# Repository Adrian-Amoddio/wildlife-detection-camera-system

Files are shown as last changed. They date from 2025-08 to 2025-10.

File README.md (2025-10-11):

# Wildlife Camera System



## Demo Video

Watch the demo (https://youtu.be/tZjDdPRHNxE)  
[▶ **Watch on YouTube**](https://youtu.be/tZjDdPRHNxE)

I designed and built a fully off grid, solar powered wildlife monitoring system. It can stream live video, log environmental data, and trigger my Canon EOS R6 for high-resolution stills remotely from anywhere with mobile reception.

The system operates with a Raspberry Pi 5, Python/Flask backend, a React dashboard for camera / mode control and monitoring, and an AWS EC2 instance for streaming with a dockerized NGINX server with RTMP to HLS conversion. I created everything myself and handled: picking the hardware, designing and fabricating the case, electronics wiring, networking, coding the APIs, and coding the front end website.

The goal was to create a drop and leave anywhere device for photographing and researching wildlife in places that are hard to reach without having to hike back in to retrieve data or pickup heavy gear.

As an improvement to the project, I recently added a YOLOv8 animal detection prototype script that can detect various species of wildlife. Once deployed to the Pi, the system has the potential to selectively take photographs only of animals of interest and categorise them accordingly.

Tech Summary: Raspberry Pi 5, Python, Flask, React, AWS EC2, Docker, NGINX RTMP/HLS, I²C sensor integration, Linux, CAD, Hands on Fabrication

---

## Tech Stack

- **Hardware:** Raspberry Pi 5 (8GB), Pi Camera Module 3 Wide, Canon EOS R6 , PicoDev BMP280 sensor
- **Pi software:** Python 3.11, `libcamera`, `ffmpeg`, `gphoto2`
- **Backend (EC2):** Dockerized NGINX RTMP/HLS streaming server, Flask API for recieving sensor data
- **Frontend:** React with Recharts, live video stream, environmental telemetry, Canon R6 capture, able to toggle modes
- **Protocols:** RTMP to HLS, REST (JSON), I²C
- **Power and Enclosure:** LiFePO₄ battery, solar panel, custom lens port and weather proof case

---

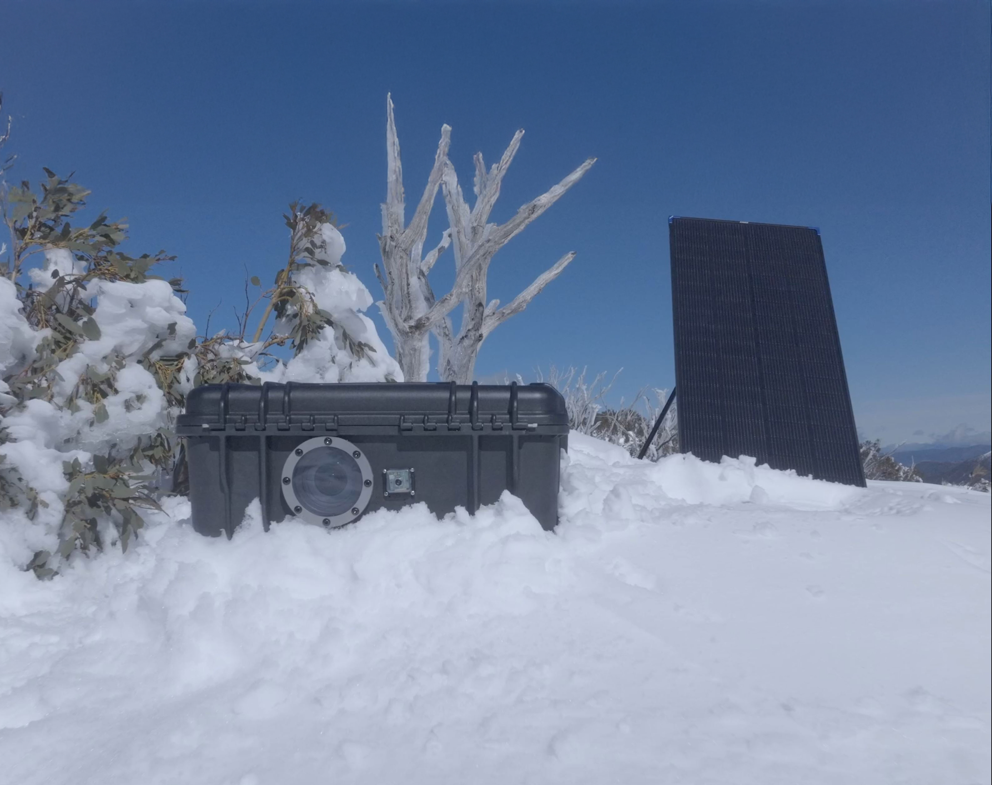
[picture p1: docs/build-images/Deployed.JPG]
Build photo
## 

### Final UI Screenshots

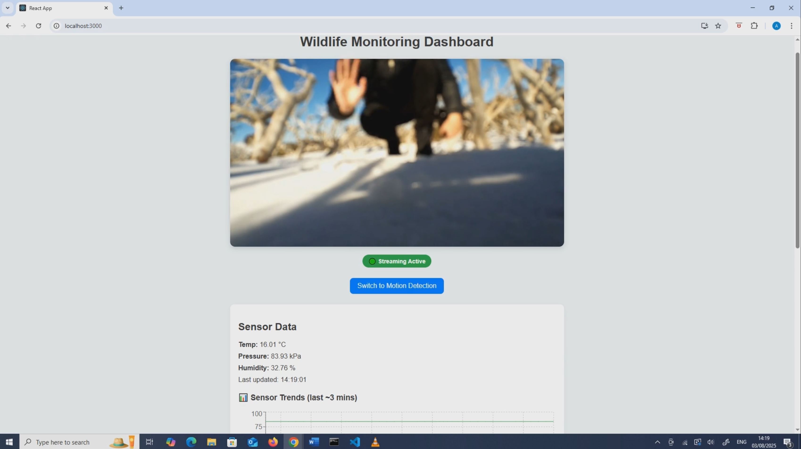
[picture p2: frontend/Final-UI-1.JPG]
Final UI - Stream View

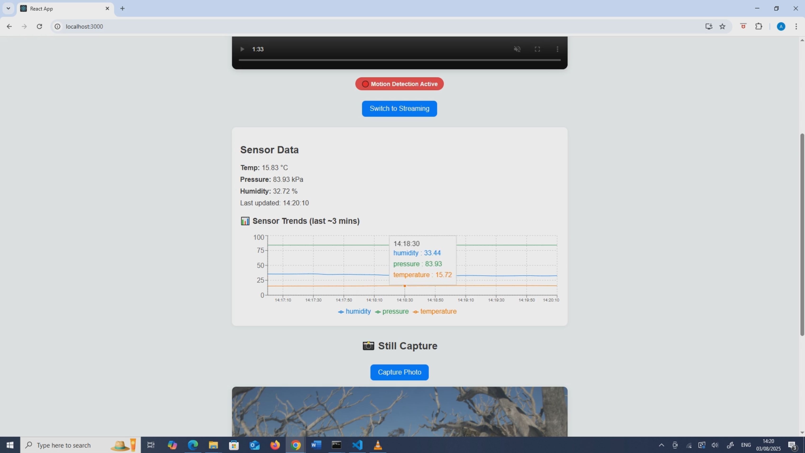
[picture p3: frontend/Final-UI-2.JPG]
Final UI - Sensor Data

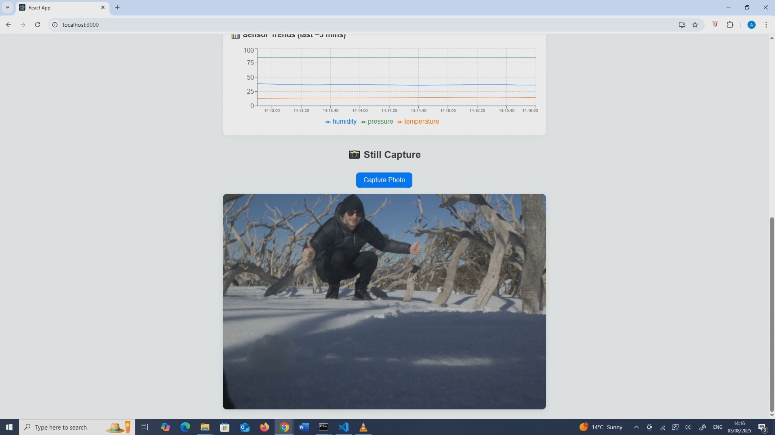
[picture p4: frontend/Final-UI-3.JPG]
Final UI - Capture Function


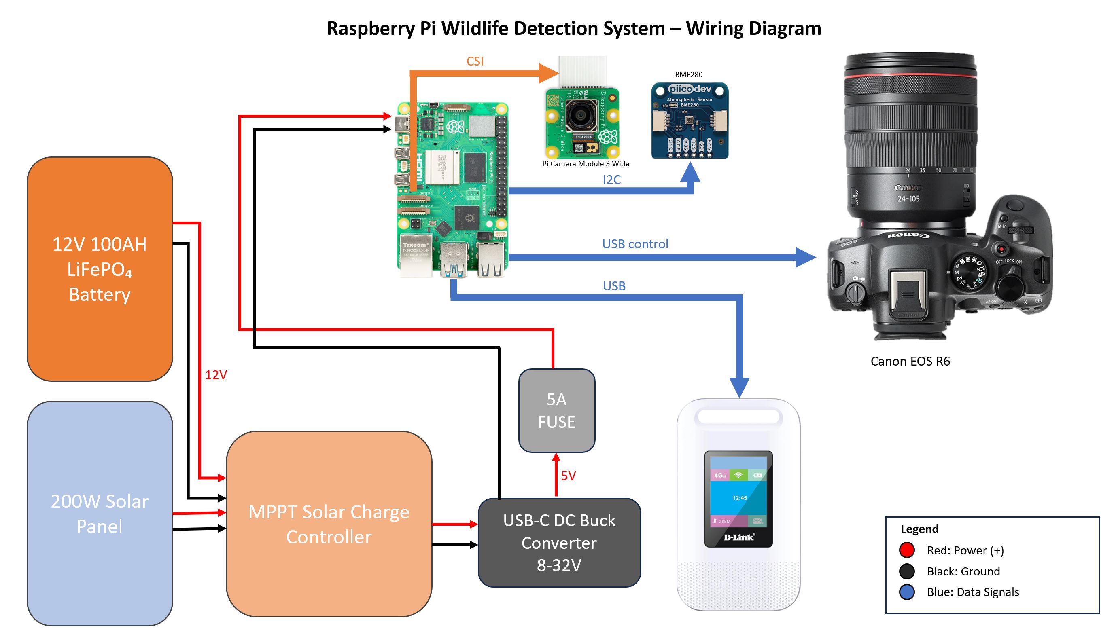
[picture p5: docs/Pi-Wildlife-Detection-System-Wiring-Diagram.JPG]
Wiring Diagram
## 

---

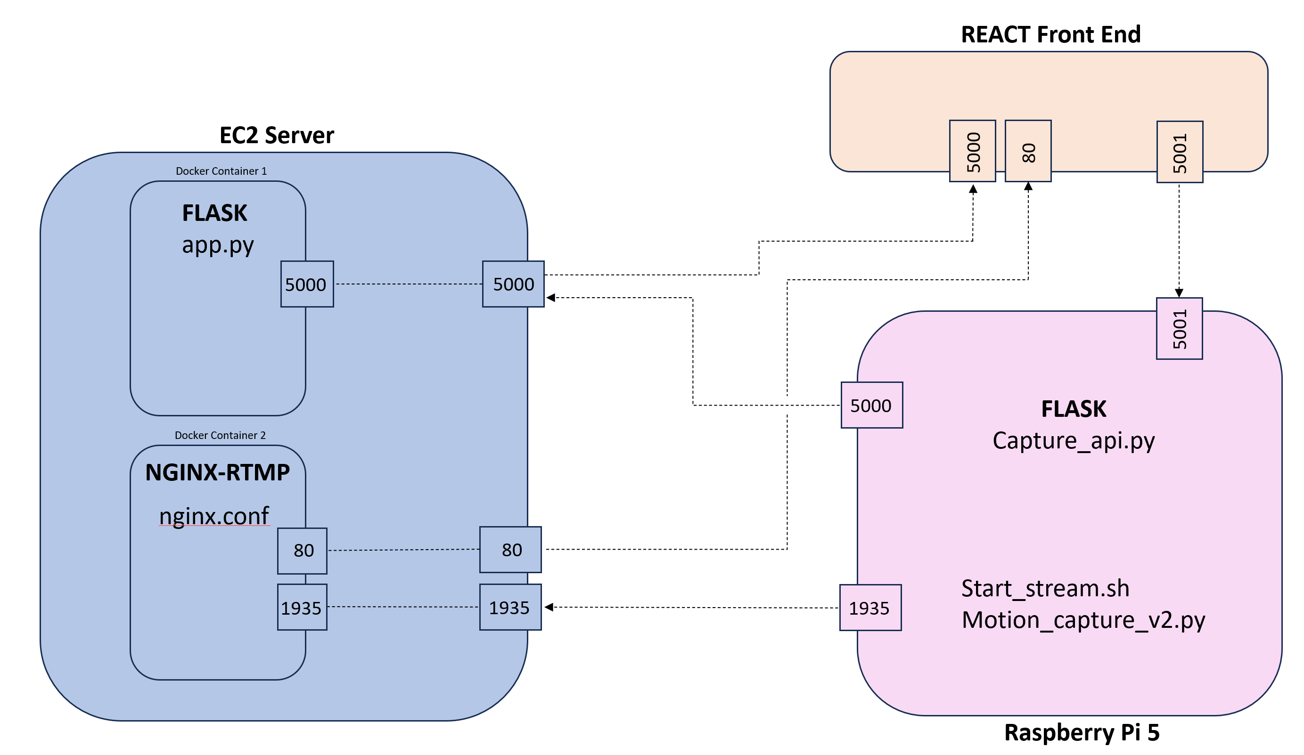
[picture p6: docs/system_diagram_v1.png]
Data Flow Diagram
## 

---

## What it does

- **Live stream**: Low-latency HLS stream from the Pi → EC2 → React front end
- **Motion detection**: Triggers the R6 for high-resolution stills (or you can capture manually).
- **Telemetry**: Temperature, pressure, humidity via BMP280 with charts where you can view the data.
- **Mode switching**: Toggle **Motion** ↔ **Streaming** from the dashboard.
- **Smart and Reliable UX**: Sensor polling, stream retry logic, and clear error states in the UI.

> **My role:** I designed and implemented the **entire system**—hardware choices, enclosure, Pi scripts, EC2 services, and the React frontend.

---

## AI Object Detection Prototype

To extend the system toward AI integration, I added a prototype object detection module using [YOLOv8](https://github.com/ultralytics/ultralytics).  
This prototype demonstrates how the camera feed could be enhanced with real-time wildlife recognition.

- **Model:** YOLOv8n 
- **Demo:** Script run on sample animal images, with annotated outputs saved in [`object_detection/runs/detect/pi_demo`](object_detection/runs/detect/pi_demo)  
- **Future plan:** Deploy YOLO models directly on the Raspberry Pi or stream frames to the EC2 server. Fine-tune models for Australian wildlife species (e.g. deer, snow fox, wombats, bird species).

**Example output:**

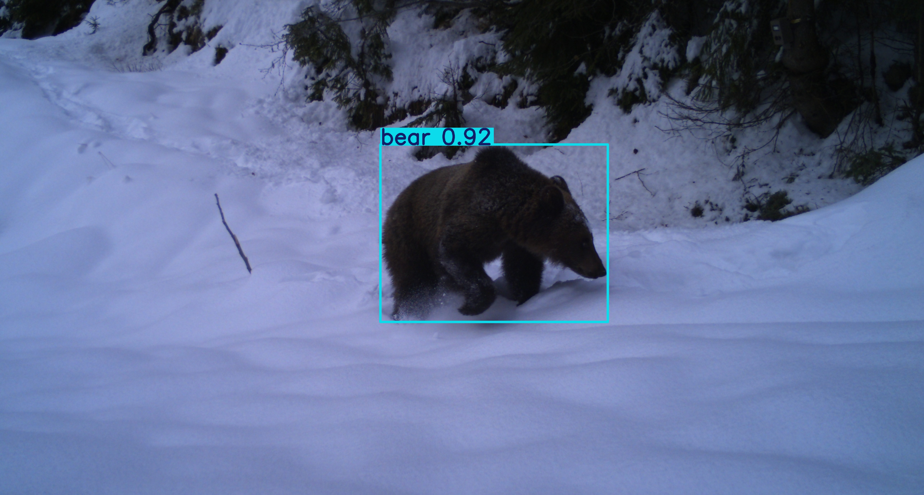
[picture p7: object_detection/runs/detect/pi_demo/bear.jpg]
Object Detection Example


---

## Project Structure

```
├── captures/                     # Optional saved test images or videos
│
├── docs/                          # Build images and final deployed photograph
│   ├── Pi-Wildlife-Detection-System-Wiring-Diagram.JPG
│   └── build-images/
│       ├── 1.jpg … 40.jpg
│       ├── AlFlange.JPG
│       └── Deployed.JPG
│
├── ec2-server/                    # Backend scripts and dockerfile for video stream and sensor data
│   ├── environmental_sensor/      # Flask API for sending BMP280 sensor data to the EC2 server
│   │   ├── app.py
│   │   ├── Dockerfile.txt
│   │   └── requirements.txt
│   │
│   └── nginx-rtmp/                 # RTMP/HLS server
│       ├── docker-compose.yml
│       ├── nginx.conf
│       └── nginx-hls/              # RTMP to HLS Docker build for NGINX
│
├── frontend/                      # Front End React Website
│   └── react-frontend/
│       ├── player.html
│       ├── styles.css
│       └── pi-stream-ui/
│           ├── .env.example
│           ├── package.json
│           ├── public/
│           └── src/
│
├── object_detection/            # Inludes sample images and results that demo the animal detection model
│   ├── runs/
│   ├── samples/
│   └── detect.py

├── hardware/                      # CAD/drawings for custom lens port for Canon R6
│   ├── acrylic-flange-files/
│   ├── aluminium-flange-files/
│   └── pmma-flange-files/
│
└── pi/                            # All scripts that run on the Pi for the different functions of the device
    ├── capture_api.py              # Remote still photo capture with the Canon EOS R6
    ├── motion_trigger_picamera2.py # Motion detection script that triggers the R6
    ├── send_sensor_data.py         # Sends sensor data to the EC2 backend
    ├── start_stream.sh             # Used whenever the user switches into streaming mode. Cannot run when other scripts are accessing the pi camera 3 wide
    └── requirements.txt
```

---

## Hardware

- Raspberry Pi 5 8GB
- Pi Camera Module 3 Wide
- Canon EOS R6 with 24–70mm f2.8 RF lens
- Picodev BMP280 environmental sensor
- D-Link Cat6 Mobile Hotspot
- Kings 12V LiFePO4 battery
- Kings 200W Solar Panel
- Kings Anderson Solar Extension Cable
- Dune MPPT Solar Charge Controller
- Tactix Black Extra Large Tough Case
- Custom camera lens port (see `/hardware/`)
- 2 × 6mm Waterproof cable glands

---

## Software

- Raspberry Pi OS (Bookworm or later, 64-bit)
- Python 3.11+
- `libcamera`
- `gphoto2`
- `ffmpeg`
- AWS EC2 backend (NGINX RTMP/HLS + Flask API)

---

## Installation

1. **Clone this repository** onto your Pi 5:

   ```bash
   git clone https://github.com/Adrian-Amoddio/wildlife-detection-camera-system.git
   cd wildlife-detection-camera-system/pi
   ```

2. **Install Python dependencies**:

   ```bash
   python3 -m venv venv
   source venv/bin/activate
   pip install -r requirements.txt
   ```

3. **Install system dependencies**:

   ```bash
   sudo apt update
   sudo apt install ffmpeg gphoto2 python3-pip libatlas-base-dev
   ```

4. **Configure environmental sensor**:

   - Ensure the BMP280 is connected via I²C
   - Enable I2C on the Pi:
     ```bash
     sudo raspi-config
     # Interfacing Options - I2C - Enable
     ```
   - Verify it’s detected:
     ```bash
     sudo apt install -y i2c-tools
     i2cdetect -y 1
     ```

5. **Set environment variables** (optional):
   - Create a `.env` file:
     ```bash
     SENSOR_API_URL=https://<ec2-server-ip>/sensor
     RTMP_SERVER_URL=rtmp://<ec2-server-ip>/live/stream
     ```

---

## Scripts Overview

- **capture_api.py** – Flask API to trigger still capture from the Canon EOS R6. Then return and save the image.
- **motion_trigger_picamera2.py** – Uses Pi Camera Module 3 Wide for motion detection to trigger R6 still capture or switch to streaming.
- **send_sensor_data.py** – Reads temperature, pressure, and humidity from BMP280 and sends JSON to EC2 backend every 10 seconds.
- **start_stream.sh** – Launches live streaming pipeline and sends to EC2 instance.

---

## Usage

### Start live stream

```bash
chmod +x start_stream.sh
./start_stream.sh
```

### Run environmental sensor loop

```bash
python3 send_sensor_data.py
```

### Run motion detection

```bash
python3 motion_trigger_picamera2.py
```

### Start capture API server

```bash
python3 capture_api.py
```

Trigger remote capture:

```bash
curl -X POST http://<pi-ip>:5000/capture
```

---

## Recommended Deployment

The scripts below need to be run on boot if you want the system to operate independantly. It is recommended you do this as running anything manually in remote areas is difficult.

- `capture_api.py`
- `send_sensor_data.py`

---

## Streaming Pipeline (RTMP converted to HLS)

The Pi streams video via **RTMP** to an **NGINX server** running on my EC2 instance. This server is inside a Docker container and uses the **NGINX RTMP module** to convert the incoming stream into **HLS**. The frontend React app then pulls the `.m3u8` playlist from the server to display the live video in the browser. The reason why I converted the stream from RTMP to HLS is because browsers do not natively support RTMP streams. HLS is natively supported in most browsers.

- The NGINX config and Docker setup are located in `ec2-server/nginx-rtmp/`
- The stream can be viewed from anywhere by accessing the React frontend
- During local testing, I used a prebuilt Windows release of NGINX with RTMP from [Broukmiken/Nginx.exe-RTMP](https://github.com/Broukmiken/Nginx.exe-32-and-64-bits-With-RTMP/releases/tag/v1.24.4) for fast iteration before deploying the Docker version to AWS

---

## Notes

- The motion detection and video screaming scripts cannot run simultanously. Only one can run at a time other wise this will cause an error or the pi will crash
- Canon EOS R6 must be powered on and connect with a USB to the Pi
- Ensure the EC2 instance is running before running any scripts on the pi or trying to access the front end.

---

## Personal Note

I am an engineer with a passion for embedded systems and photography. I wanted to make this project to demonstrate my skills and create something I can use for photography projects which can be used anywhere in the world to capture hard to reach places, scenes or wildlife. You can use the system to research behavioural and location analysis of wildlife and correlate that data against environmental parameters like: temperature, pressure and humidity. What's more you don't have to wait to retrieve the results you can access them instantly online and don't have to trek back into the wild to pickup any gear.

Future updates will include an advanced motion detection algorithm that can be remotely updated with a trained AI model to more specifically detect wildlife and events of interest.

## Setup References

- [Raspberry Pi scripts](pi/README.md)
- [EC2 backend](ec2-server/README.md)
- [Frontend UI](frontend/react-frontend/pi-stream-ui/README.md)

---

## License

MIT License — free to use, modify, and distribute.

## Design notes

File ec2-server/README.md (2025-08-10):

# EC2 Server Backend

This folder contains all scripts and code for the EC2 instance used in the Wildlife Detection Camera System. It includes two main components:

- app.py - Flask server to receive and serve sensor data.
- NGINX RTMP Server - Used to relay live HLS video streams from the Raspberry Pi.

## Folder Structure

```
ec2-server/
├── environmental_sensor/
│   ├── app.py
│   ├── Dockerfile
│   └── requirements.txt
│
├── nginx-rtmp/
│   ├── nginx.conf          # RTMP and HLS server config for NGINX
│   ├── docker-compose.yml
│   └── nginx-hls/
```

## Deployment Notes

- The **NGINX container** exposes ports `80` and `1935`. It mounts:

  - `nginx.conf` to `/etc/nginx/nginx.conf`
  - `nginx-hls/` to `/opt/data/hls`

- The **Flask environmental sensor API** runs on port `5000` by default and supports:
  - `POST /sensor` — Accepts sensor readings as JSON.
  - `GET /sensor` — Returns latest received sensor data.

## Prerequisites

- EC2 instance running Ubuntu (or similar Linux)
- Docker + Docker Compose installed
- Open ports:
  - **1935** for RTMP ingest from the Pi
  - **80** for HLS playback to the frontend

## Setup

To run the NGINX container:

```bash
cd nginx-rtmp/
sudo docker-compose up -d
```

To build and run the Flask relay (optional if containerized):

```bash
cd environmental_sensor/
pip install -r requirements.txt
python app.py
```

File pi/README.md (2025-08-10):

# Raspberry Pi Backend

This folder contains the scripts and code for the Raspberry Pi 5 used in the Wildlife Detection Camera System. It handles camera control, motion detection, sending sensor data, and live video streaming.

## Folder Structure

```
pi/
├── capture_api.py               # Flask API
├── motion_trigger_picamera2.py  # Script for continuous motion detection and triggering the Canon R6
├── start_stream.sh               # Starts the video stream from the Pi
├── send_sensor_data.py           # Sends temperature, pressure and humidity data to EC2 server
├── requirements.txt
└── README.md
```

## Key Functions

- **capture_api.py** — Provides REST endpoints to control capture modes and take high-resolution photos.
- **motion_trigger_picamera2.py** — Runs motion detection and triggers the camera.
- **start_stream.sh** — Starts an HLS stream via `ffmpeg`.
- **send_sensor_data.py** — Reads sensor values and sends them to the EC2 backend.

## Setup

1. Install dependencies:

   ```bash
   pip install -r requirements.txt
   ```

2. Start the capture API:

   ```bash
   python3 capture_api.py
   ```

3. (Optional) Start motion detection:

   ```bash
   python3 motion_trigger_picamera2.py
   ```

4. (Optional) Start live streaming:
   ```bash
   ./start_stream.sh
   ```

## Notes

- Works with Canon EOS R6 connected via USB and `gphoto2`.
- `.cr3` RAW images are automatically converted to `.jpg` for storage or upload.

## License

This project is licensed under the [MIT License](../LICENSE).

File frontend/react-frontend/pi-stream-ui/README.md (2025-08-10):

# Frontend

This folder contains the React website for the Wildlife Detection Camera System.  
It connects to the EC2 server to display live video and sensor data from the Raspberry Pi.

## Folder Structure

```
frontend/
└── react-frontend/
    └── pi-stream-ui/
        ├── public/
        ├── src/
        ├── package.json
        ├── package-lock.json
        ├── .env.example           # Example environment variables
        └── README.md
```

## Key Features

- Displays live HLS video from the EC2 streaming server.
- Shows temperature, pressure and humidity data from the Pi 5
- Simple, responsive UI for system control and monitoring the environement

## Setup

1. Install dependencies:

   ```bash
   npm install
   ```

2. Create an `.env` file based on `.env.example` and update it with your backend URLs and IPs.

3. Start the development server (local testing only):

   ```bash
   npm start
   ```

   This runs the app at `http://localhost:3000` for development purposes.  
   Note: In production, the frontend can be hosted on any server (including remote/cloud hosting) and accessed from anywhere. It is not limited to local network use.

4. Open `http://localhost:3000` in your browser.

## Build for Production

```bash
npm run build
```

The production build will be output to the `build/` directory and can be served via any static file server.

## License

This project is licensed under the [MIT License](../LICENSE).

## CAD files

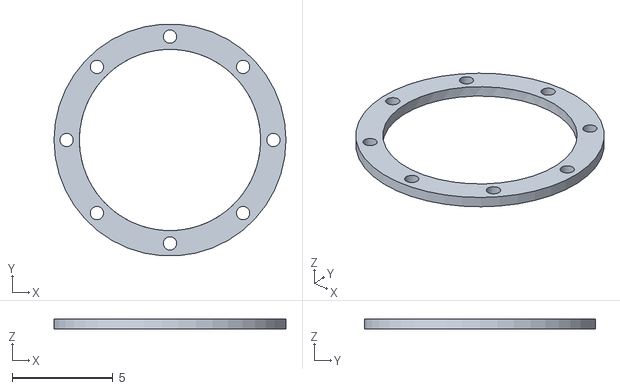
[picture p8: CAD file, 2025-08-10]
hardware/aluminium-flange-files/Aluminium_Flange_v2.obj
11.5 x 11.5 x 0.5

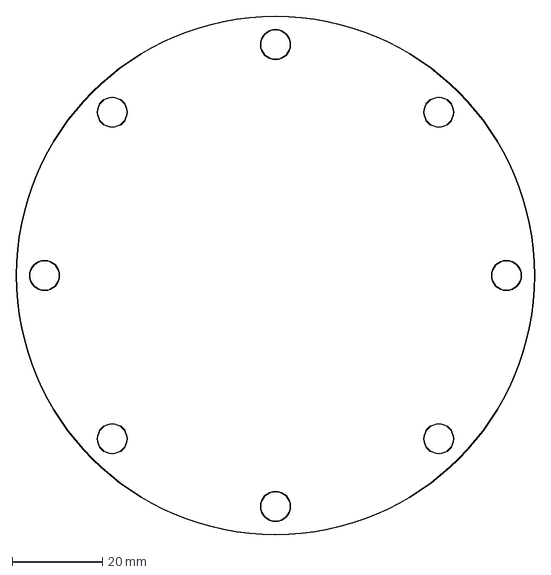
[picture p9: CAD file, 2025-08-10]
hardware/pmma-flange-files/PMMA_Flange_v2.dxf
115.0 x 115.0 mm

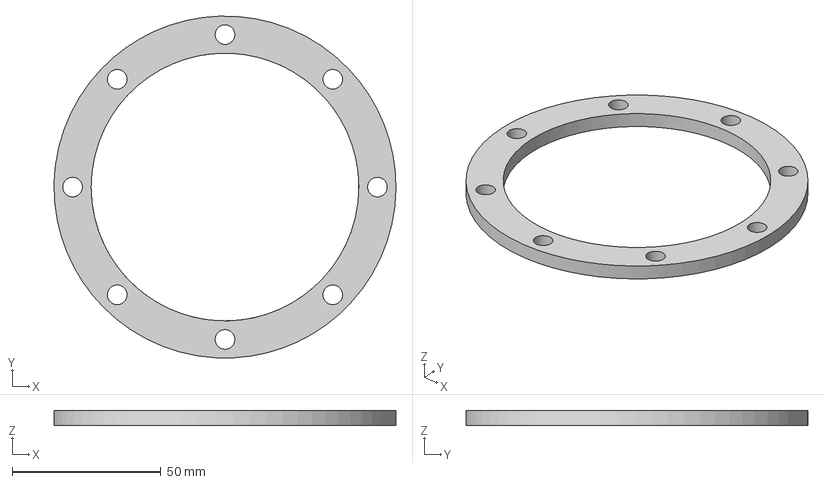
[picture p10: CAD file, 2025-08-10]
hardware/aluminium-flange-files/Aluminium_Flange.iges
115.0 x 114.9 x 5.00 mm

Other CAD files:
hardware/acrylic-flange-files/Acrylic_Flange.FCStd
hardware/aluminium-flange-files/Unnamed-Aluminium_Flange.step
hardware/aluminium-flange-files/Aluminium_Flange_v2.dxf

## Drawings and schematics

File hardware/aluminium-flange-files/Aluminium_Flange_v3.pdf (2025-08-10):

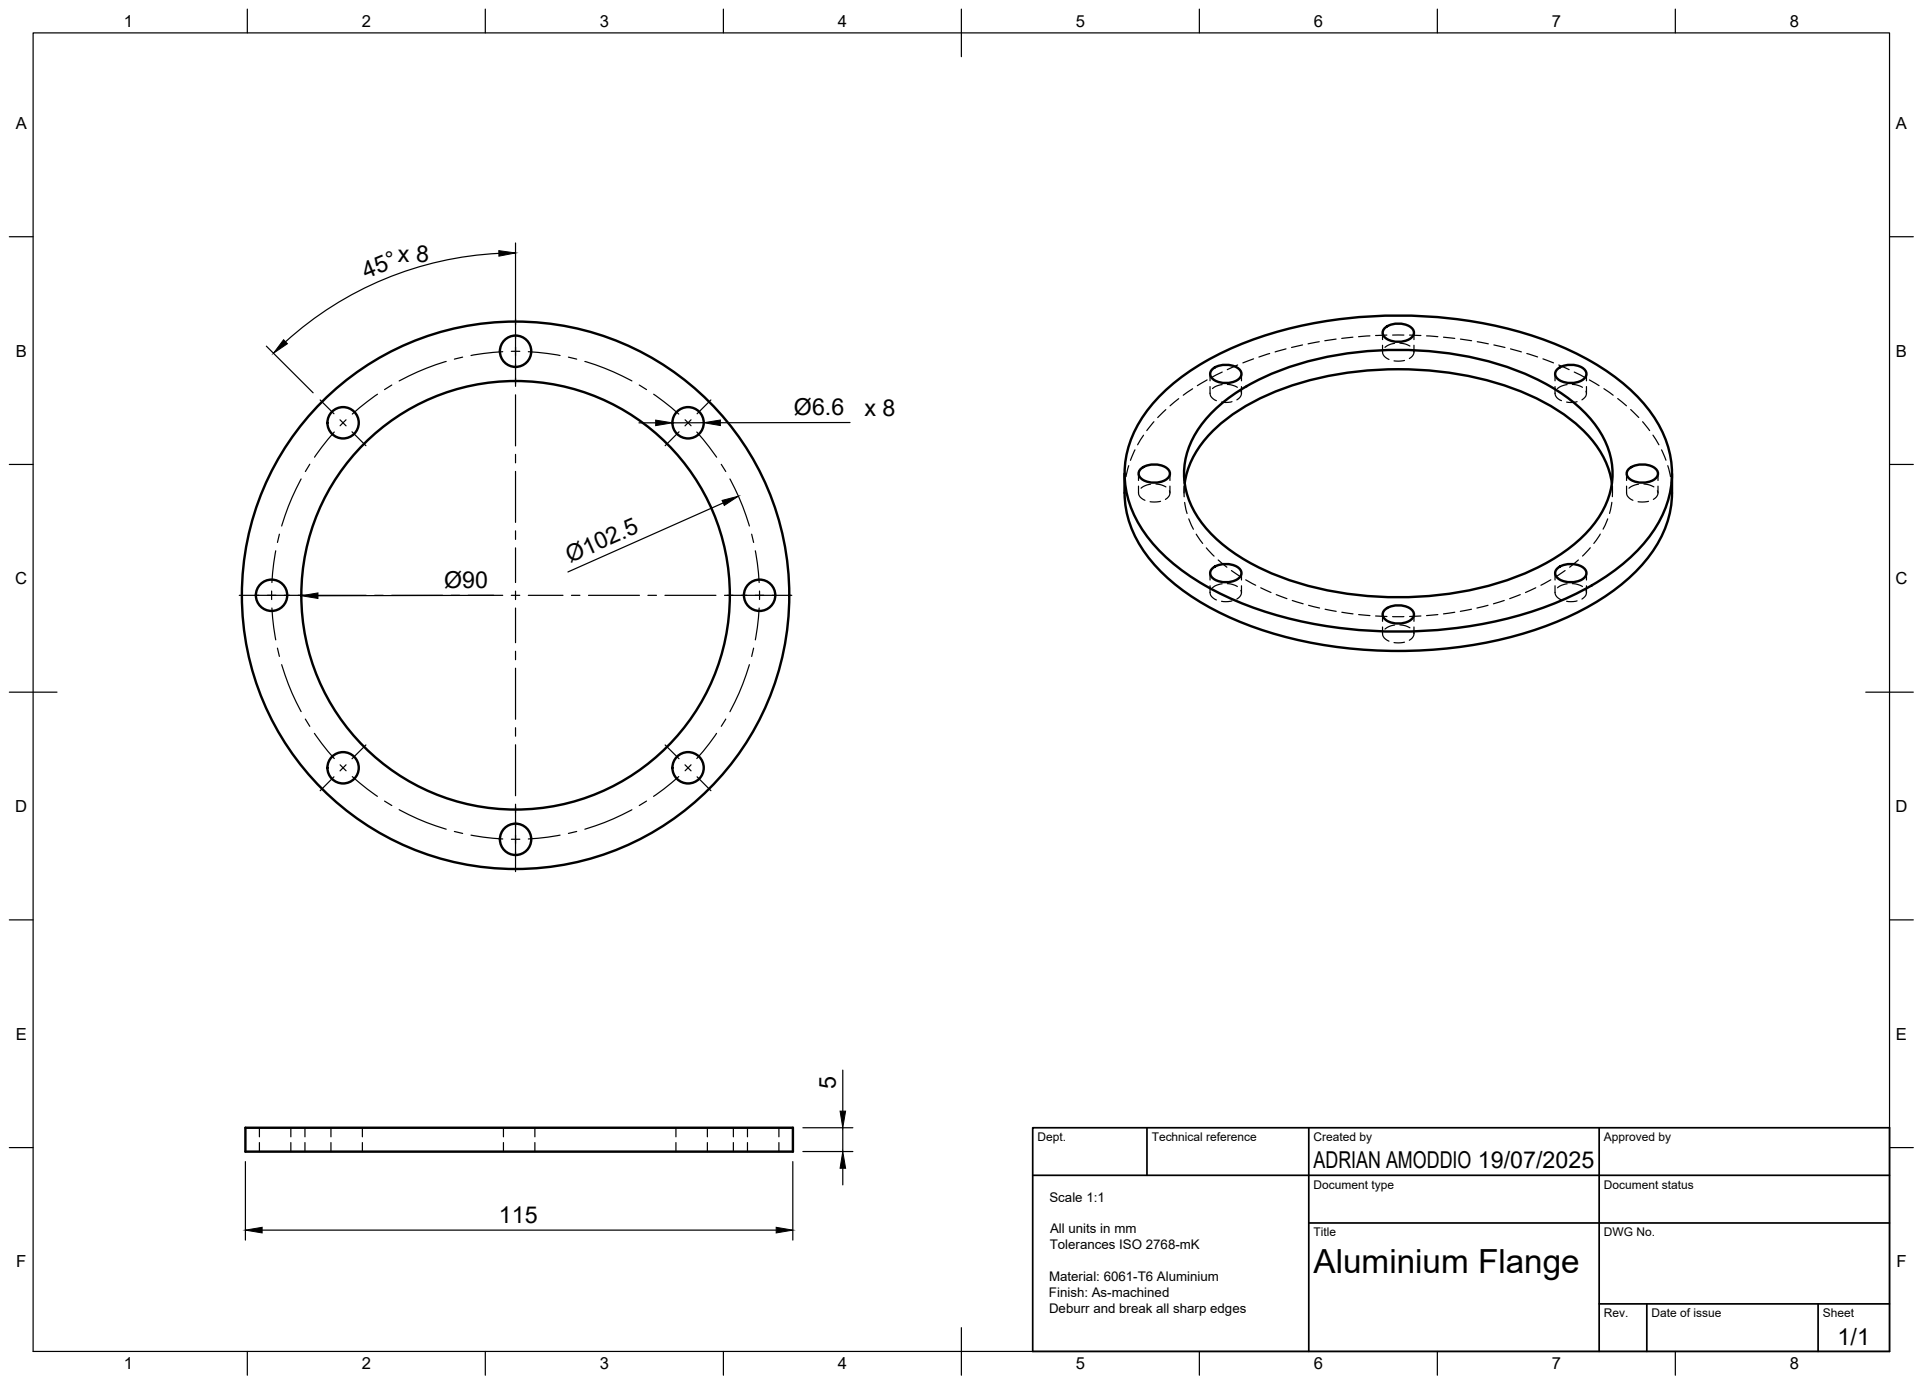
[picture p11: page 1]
Title; DWG No.; Rev.; Date of issue; Sheet; Aluminium Flange; Scale 1:1

Dept. | Technical reference | Created by ADRIAN AMODDIO 19/07/2025 | Approved by

Document type | Document status

All units in mm
Tolerances ISO 2768-mK

Material: 6061-T6 Aluminium
Finish: As-machined
Deburr and break all sharp edges

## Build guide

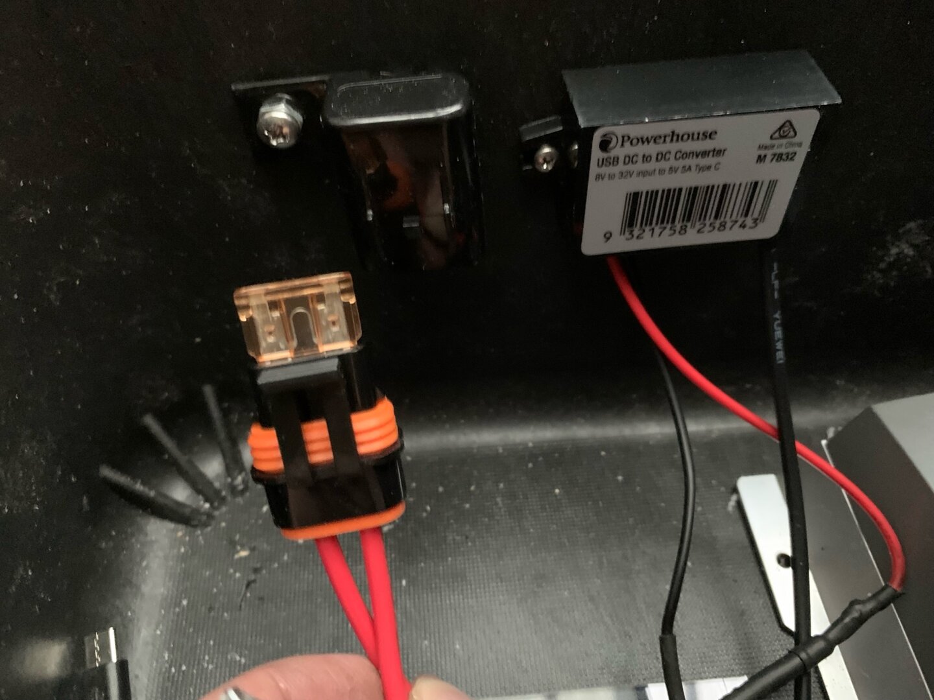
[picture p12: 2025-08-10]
docs/build-images/32.jpg

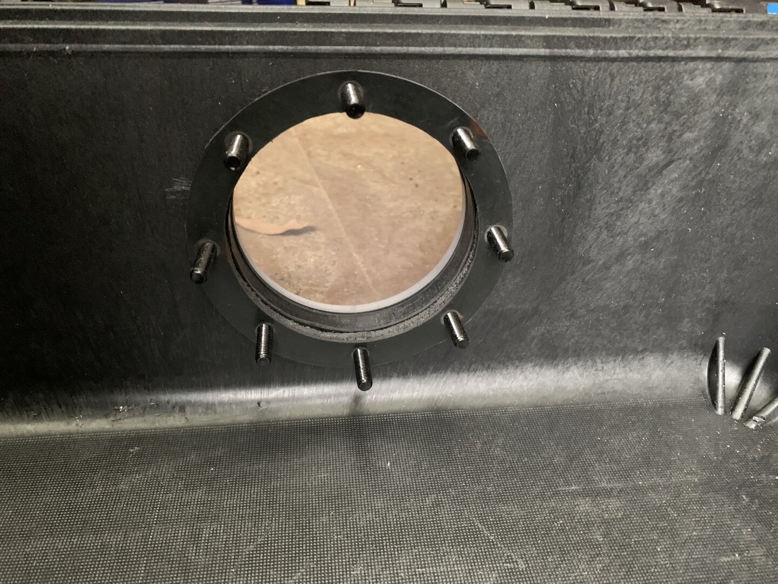
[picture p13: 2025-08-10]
docs/build-images/15.jpg

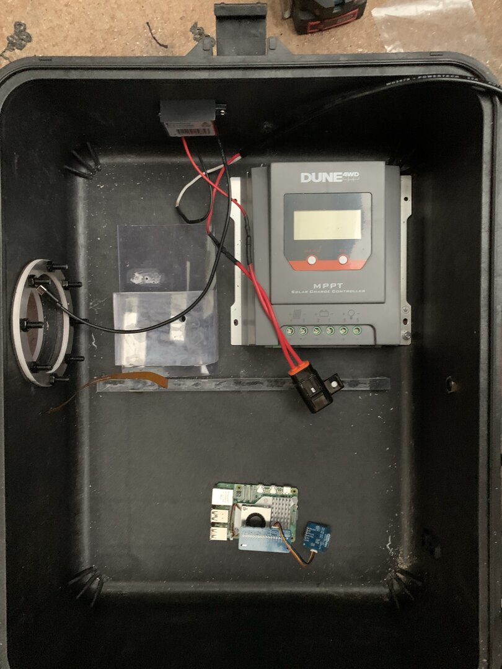
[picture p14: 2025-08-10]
docs/build-images/23.jpg

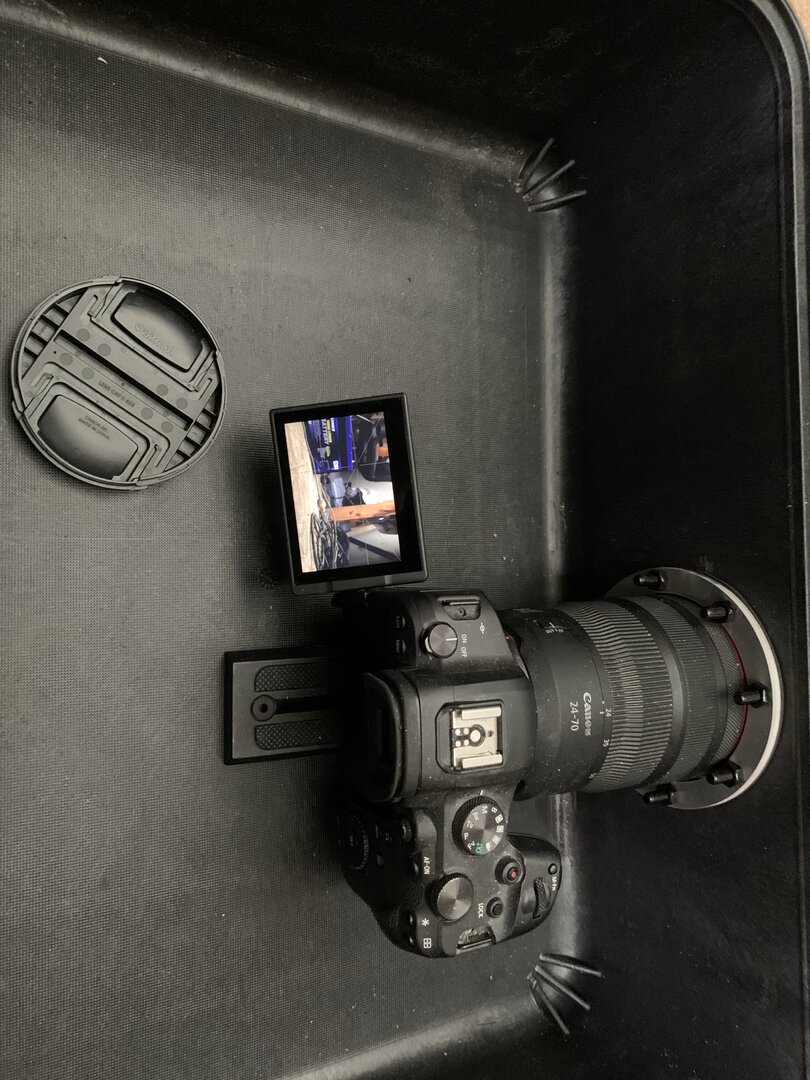
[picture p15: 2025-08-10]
docs/build-images/20.jpg

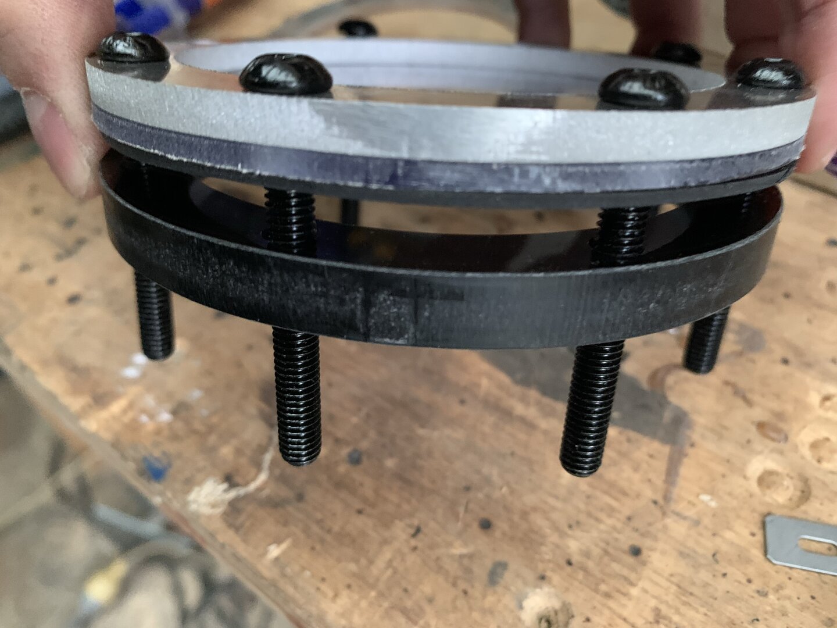
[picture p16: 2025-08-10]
docs/build-images/5.jpg

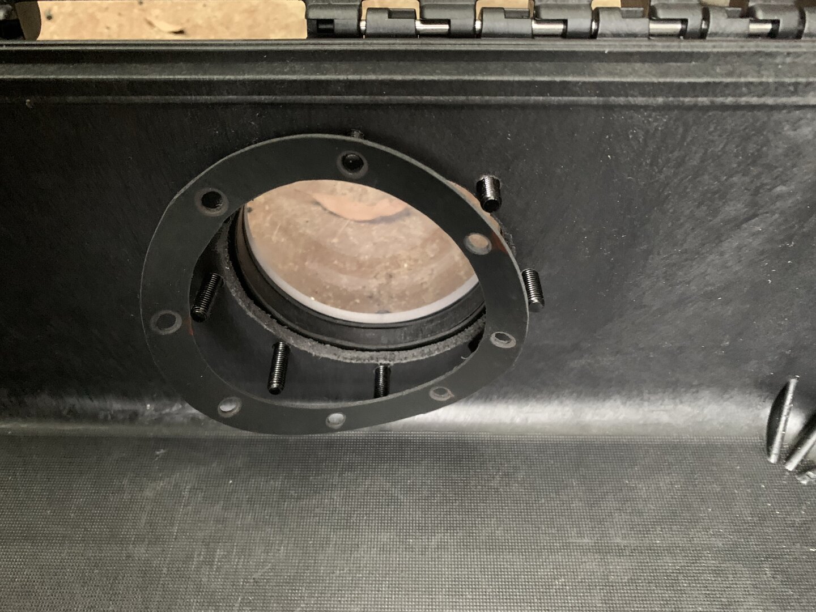
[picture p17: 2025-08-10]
docs/build-images/14.jpg

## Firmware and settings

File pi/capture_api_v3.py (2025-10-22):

#!/usr/bin/env python3
from flask import Flask, jsonify, send_file, request
from flask_cors import CORS
import subprocess
import os
import time
import signal
import logging
import shutil
from pathlib import Path
from typing import Optional, List, Dict

# ----------------------------------------------#
from ultralytics import YOLO
import cv2
import numpy as np

# -----------------------------------------------------------------------------
# App setup
# -----------------------------------------------------------------------------
app = Flask(__name__)
CORS(app, resources={r"/*": {"origins": "*"}})

logging.basicConfig(level=logging.INFO, format="%(asctime)s %(levelname)s %(message)s")

# Directories and files
CAPTURE_DIR = "/home/pi5-01/captures"
MODE_FILE = "/tmp/current_mode"
MOTION_PID_FILE = "/tmp/motion_pid"
STREAM_PID_FILE = "/tmp/stream_pid"
STREAM_SCRIPT = "/home/pi5-01/start_stream.sh"
MOTION_SCRIPT = "/home/pi5-01/motion_trigger_picamera2.py"

# Where annotated previews are saved for the frontend
STATIC_DIR = "/home/pi5-01/static"
LATEST_JPG = os.path.join(CAPTURE_DIR, "latest.jpg")

os.makedirs(CAPTURE_DIR, exist_ok=True)
os.makedirs(STATIC_DIR, exist_ok=True)

# --- EDIT ME: default labels to keep when clicking AI Detect ---
SERVER_LABEL_FILTER: List[str] = ["refrigerator", "dog", "bird"]

# YOLO model (lazy-loaded)
MODEL_PATH = "yolov8n.pt"
_yolo_model: Optional[YOLO] = None

latest_sensor_data = None

# -----------------------------------------------------------------------------
# Helpers
# -----------------------------------------------------------------------------
def json_error(message: str, status: int = 500):
    return jsonify({"ok": False, "status": "error", "message": message}), status


def get_model() -> YOLO:
    global _yolo_model
    if _yolo_model is None:
        app.logger.info("Loading YOLO model: %s", MODEL_PATH)
        _yolo_model = YOLO(MODEL_PATH)
    return _yolo_model


def _camera_still_cmd() -> str:
    if shutil.which("rpicam-still"):
        return "rpicam-still"
    if shutil.which("libcamera-still"):
        return "libcamera-still"
    raise FileNotFoundError("No Pi camera CLI found (rpicam-still or libcamera-still)")


def _label_matches(label: str, label_filter: Optional[List[str]]) -> bool:
    if not label_filter:
        return True
    return any(label.lower() == f.lower() for f in label_filter)


def _draw_boxes(img: np.ndarray, detections: List[Dict]) -> np.ndarray:
    for det in detections:
        x1, y1, x2, y2 = map(int, det["bbox"])
        label = f"{det['label']} {det['conf']:.2f}"
        cv2.rectangle(img, (x1, y1), (x2, y2), (0, 255, 0), 2)
        cv2.putText(img, label, (x1, max(y1 - 10, 10)),
                    cv2.FONT_HERSHEY_SIMPLEX, 0.6, (0, 255, 0), 2)
    return img


def _no_cache_send_file(filepath: str, mimetype: str):
    resp = send_file(filepath, mimetype=mimetype)
    resp.headers["Cache-Control"] = "no-store, no-cache, must-revalidate, max-age=0"
    resp.headers["Pragma"] = "no-cache"
    return resp


def get_mode_string() -> str:
    if not os.path.exists(MODE_FILE):
        return "unknown"
    with open(MODE_FILE) as f:
        return f.read().strip() or "unknown"


# -----------------------------------------------------------------------------
# Routes
# -----------------------------------------------------------------------------
@app.route("/capture", methods=["POST"])
def capture_photo():
    label_filter = request.json.get("labels") if request.is_json else SERVER_LABEL_FILTER
    tmp_jpg = os.path.join(CAPTURE_DIR, "tmp.jpg")
    out_path = os.path.join(STATIC_DIR, f"annotated_{int(time.time())}.jpg")

    try:
        # Capture image from Pi camera
        camera_cmd = _camera_still_cmd()
        subprocess.run([camera_cmd, "-o", tmp_jpg, "-t", "1000", "--nopreview"], check=True)

        model = get_model()
        names = model.names
        dets_kept = []
        annotated_rel = None

        # Run YOLO detection
        results = model(tmp_jpg)
        for r in results:
            for b in r.boxes:
                cls_id = int(b.cls[0])
                conf = float(b.conf[0])
                x1, y1, x2, y2 = map(float, b.xyxy[0])
                lab = names.get(cls_id, str(cls_id))
                if _label_matches(lab, label_filter):
                    dets_kept.append({
                        "label": lab,
                        "conf": round(conf, 3),
                        "bbox": [x1, y1, x2, y2]
                    })

            if len(dets_kept) > 0:
                img = cv2.imread(tmp_jpg)  # BGR
                img = _draw_boxes(img, dets_kept)
                cv2.imwrite(out_path, img)
                annotated_rel = f"/static/{os.path.basename(out_path)}"

        return jsonify({
            "ok": True,
            "count": len(dets_kept),
            "detections": dets_kept,
            "annotated_image": annotated_rel,
            "labels_used": (label_filter or "ALL")
        })

    except FileNotFoundError:
        logging.exception("Camera CLI not found")
        return json_error("Camera CLI not found. Install rpicam-apps (Bookworm) or libcamera.", 500)
    except subprocess.CalledProcessError as e:
        logging.exception("Pi camera capture failed")
        return json_error(f"Pi camera capture failed: {e}", 500)
    except Exception as e:
        logging.exception("YOLO detect failed")
        return json_error(f"YOLO detect failed: {e}", 500)
    finally:
        try:
            if os.path.exists(tmp_jpg):
                os.remove(tmp_jpg)
        except Exception:
            pass


# -----------------------------------------------------------------------------
# Static + Health
# -----------------------------------------------------------------------------
@app.route('/static/<path:filename>', methods=['GET'])
def serve_static(filename):
    abs_path = os.path.join(STATIC_DIR, filename)
    if not os.path.isfile(abs_path):
        return json_error("File not found", 404)
    return _no_cache_send_file(abs_path, mimetype="image/jpeg")


@app.route('/health', methods=['GET'])
def health():
    cams = {
        "rpicam-still": bool(shutil.which("rpicam-still")),
        "libcamera-still": bool(shutil.which("libcamera-still"))
    }
    return jsonify({
        "ok": True,
        "mode": get_mode_string(),
        "camera_cli": cams,
        "model_loaded": _yolo_model is not None,
        "server_label_filter": SERVER_LABEL_FILTER,
    })


# -----------------------------------------------------------------------------
if __name__ == '__main__':
    app.run(host='0.0.0.0', port=5001)

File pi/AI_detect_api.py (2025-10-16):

# server/app.py
# Raspberry Pi (Bookworm) + Camera Module 3 (Wide)
# Single-shot AI detection triggered by the frontend:
# React -> POST /ai/detect -> Pi grabs a frame (libcamera-still) -> YOLOv8 -> JSON + annotated image

from flask import Flask, jsonify
from flask_cors import CORS
from ultralytics import YOLO
import os, time, subprocess, cv2

app = Flask(__name__)
CORS(app)

# Store previews here so the React app can show the latest annotated result
os.makedirs("static", exist_ok=True)

# Light model for Pi; replace with your custom weights if you have them
MODEL_PATH = "yolov8n.pt"
model = YOLO(MODEL_PATH)  # ultralytics will auto-download on first run

def capture_frame_jpeg(out_path: str):
    """
    Uses Raspberry Pi's libcamera stack to capture a single JPEG.
    The --autofocus-on-capture flag works with Camera Module 3 (AF).
    Adjust width/height as desired. 1920x1080 keeps it snappy.
    """
    cmd = [
        "libcamera-still", "-n",
        "--width", "1920", "--height", "1080",
        "--autofocus-on-capture",
        "-o", out_path
    ]
    subprocess.run(cmd, check=True)

@app.get("/ai/health")
def health():
    return "ok"

@app.post("/ai/detect")
def detect():
    ts = int(time.time())
    raw_path = f"/tmp/cap_{ts}.jpg"
    out_path = f"static/detect_{ts}.jpg"

    # 1) Capture one frame from the Pi camera
    capture_frame_jpeg(raw_path)

    # 2) Run YOLOv8 once (single-shot)
    results = model.predict(source=raw_path, imgsz=640, conf=0.35, verbose=False)

    dets = []
    if results and len(results):
        r = results[0]
        names = r.names
        if r.boxes is not None and len(r.boxes) > 0:
            for b in r.boxes:
                cls_id = int(b.cls[0]); conf = float(b.conf[0])
                x1, y1, x2, y2 = map(lambda x: float(x), b.xyxy[0])
                dets.append({
                    "label": names.get(cls_id, str(cls_id)),
                    "conf": round(conf, 3),
                    "bbox": [x1, y1, x2, y2]
                })

        # 3) Save an annotated preview image the frontend can display
        annotated_rgb = r.plot()  # RGB numpy array with boxes drawn
        cv2.imwrite(out_path, cv2.cvtColor(annotated_rgb, cv2.COLOR_RGB2BGR))
    else:
        out_path = None

    return jsonify({
        "count": len(dets),
        "detections": dets,
        "annotated_image": f"/{out_path}" if out_path else None
    })

if __name__ == "__main__":
    # Bind to 0.0.0.0 so your React app can call it over LAN
    app.run(host="0.0.0.0", port=5001)

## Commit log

2025-08-10 First commit, initial release
    [Acrylic_Flange.FCStd, Aluminium_Flange.iges, Aluminium_Flange_v2.dxf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]
2025-09-30 Adding YOLOv8 animal detection prototype demo with sample animal images
2025-09-30 Updated README to include new YOLOv8 animal detection script and sample images
